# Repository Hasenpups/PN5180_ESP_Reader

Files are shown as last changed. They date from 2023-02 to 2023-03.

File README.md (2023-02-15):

[][cc-by-nc-sa]

This work is licensed under a
[Creative Commons Attribution-NonCommercial-ShareAlike 4.0 International License][cc-by-nc-sa].

[][cc-by-nc-sa]

[cc-by-nc-sa]: http://creativecommons.org/licenses/by-nc-sa/4.0/
[cc-by-nc-sa-image]: https://licensebuttons.net/l/by-nc-sa/4.0/88x31.png
[cc-by-nc-sa-shield]: https://img.shields.io/badge/License-CC%20BY--NC--SA%204.0-lightgrey.svg

## Donations / Spenden
If somebody wants to support me for upcoming projects :)  
- PayPal:  
- Amazon Giftcard: https://www.amazon.de/Amazon-Gutschein-per-E-Mail-Amazon/dp/B0054PDOV8 - stefan.riese@me.com

# PN5180 ESP reader
This reader uses a PN5180 RFID reader and a Wemos D1 mini to read RFID tags like ISO 15693.

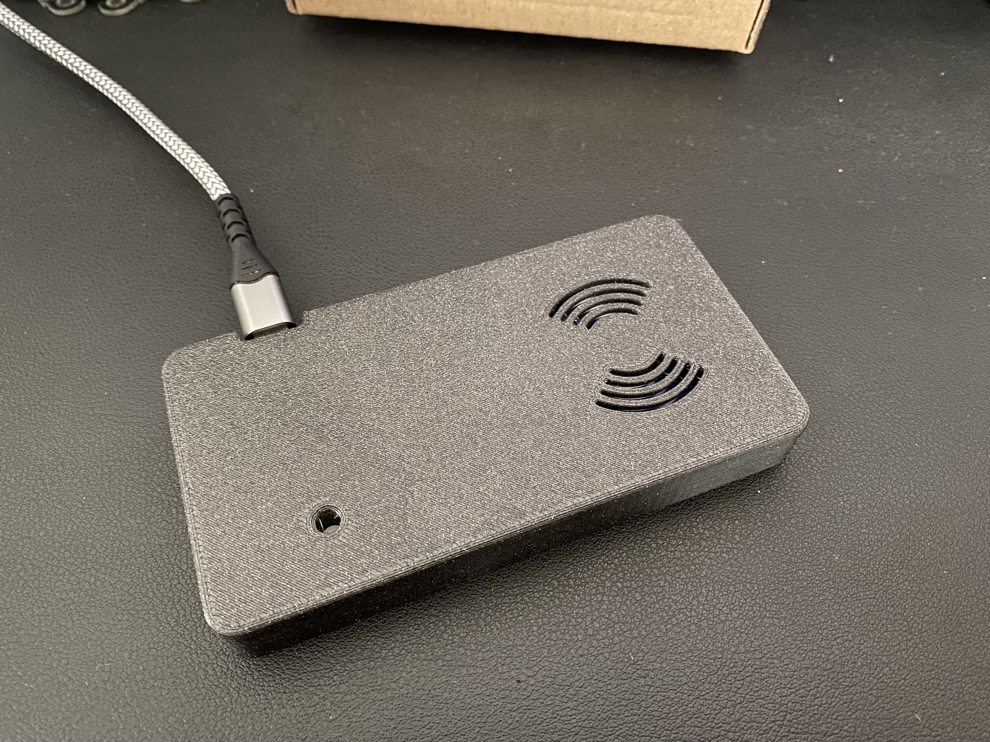
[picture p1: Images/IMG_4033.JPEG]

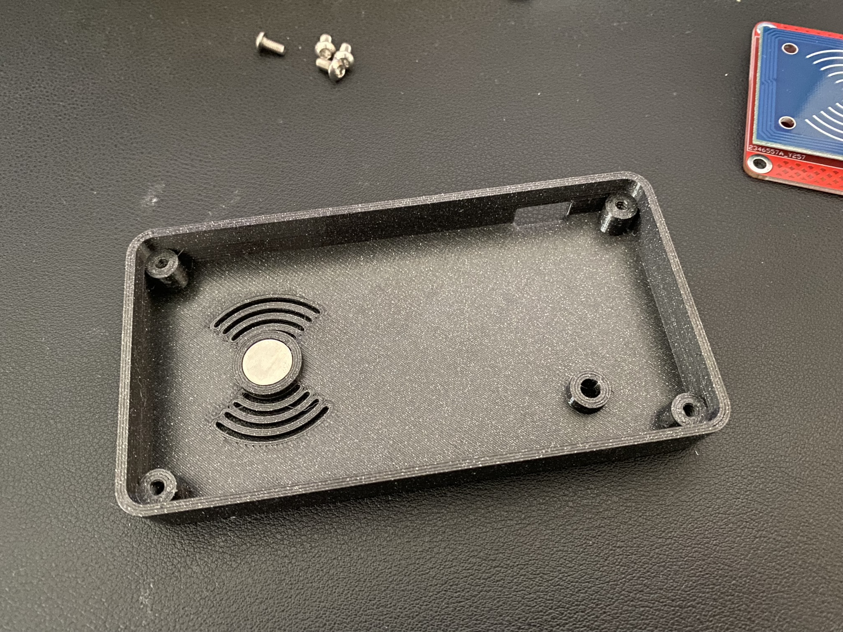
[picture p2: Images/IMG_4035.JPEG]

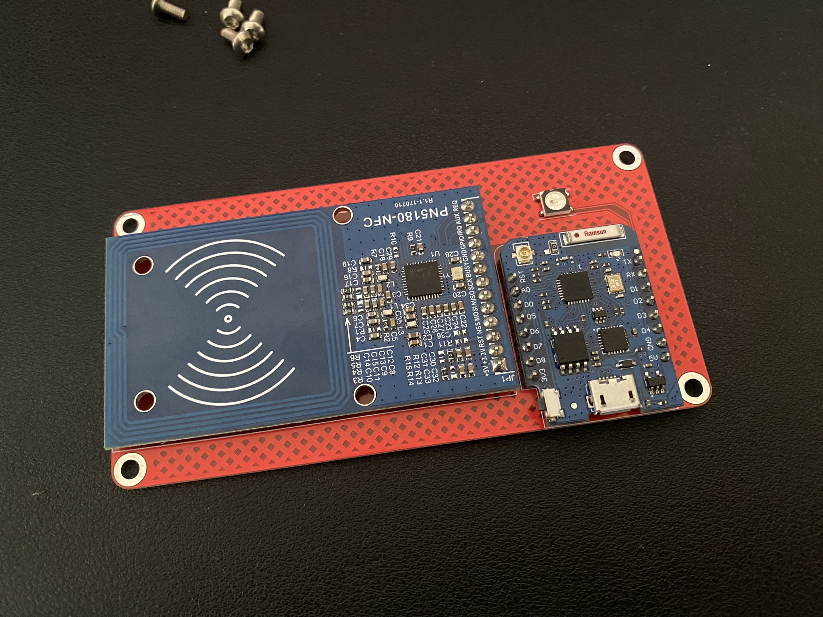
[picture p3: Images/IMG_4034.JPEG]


# Used hardware
- 1 x PN5180 reader (https://www.amazon.de/dp/B0BFGWS7MZ)
- 1 x Wemos D1 mini (https://www.amazon.de/AZDelivery-NodeMCU-ESP8266EX-kompatibel-inklusive/dp/B08BTYHJM1)
- 1 x 10x3mm magnet (https://www.amazon.de/Temporaryt-Neodym-Magnete-Aufbewahrungs-K%C3%BChlschrank/dp/B07DNBXBWQ)
- 4 x M3x6 screw

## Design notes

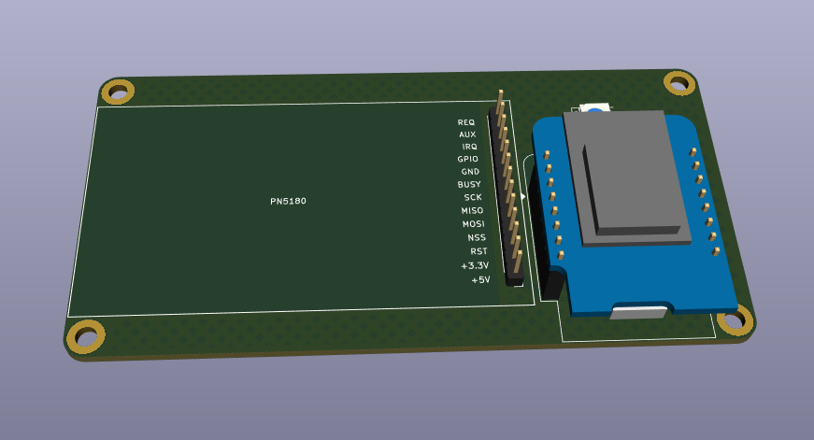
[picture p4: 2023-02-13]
PCB/PN5180_Wemos_PCB.png

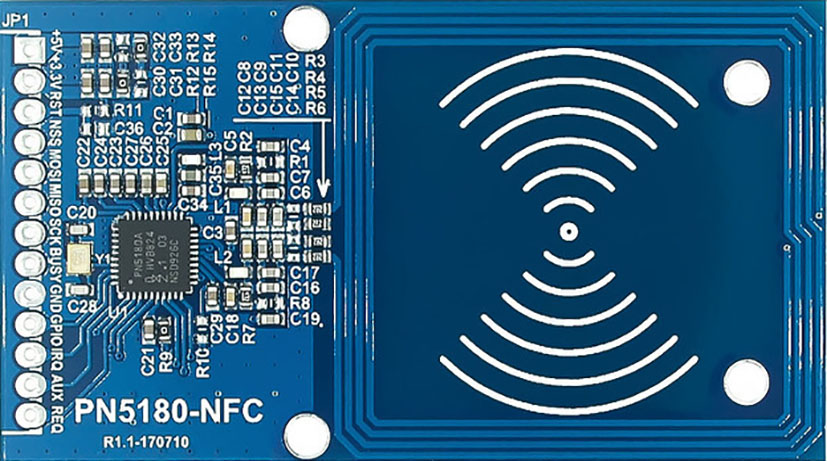
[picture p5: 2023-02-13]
PCB/PN5180-NFC-RF-Sensor-modul-Unterst-tzung-Iso15693-Hohe-Frequenz-IC-Karte-ICODE2-Reader-Schreiben.jpg

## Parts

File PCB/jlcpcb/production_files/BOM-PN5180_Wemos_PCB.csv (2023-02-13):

Comment | Designator | Footprint | LCSC
WS2812B | D1 | LED_WS2812B_PLCC4_5.0x5.0mm_P3.2mm
MountingHole | H3 | MountingHole_3.2mm_M3_DIN965_Pad
MountingHole | H2 | MountingHole_3.2mm_M3_DIN965_Pad
MountingHole | H1 | MountingHole_3.2mm_M3_DIN965_Pad
Conn_01x13_Female | PN5180 | PinHeader_1x13_P2.54mm_Vertical
WeMos_D1_mini | U1 | WEMOS_D1_mini_light
MountingHole | H4 | MountingHole_3.2mm_M3_DIN965_Pad

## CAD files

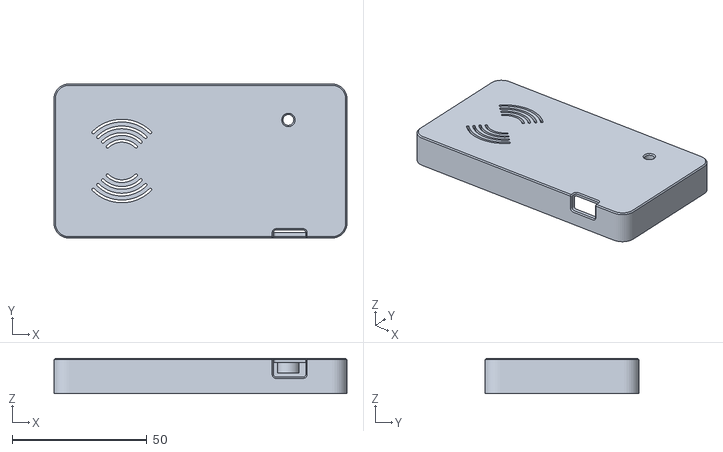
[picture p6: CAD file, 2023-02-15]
Housing/Top.stl
108.8 x 57.2 x 13.1

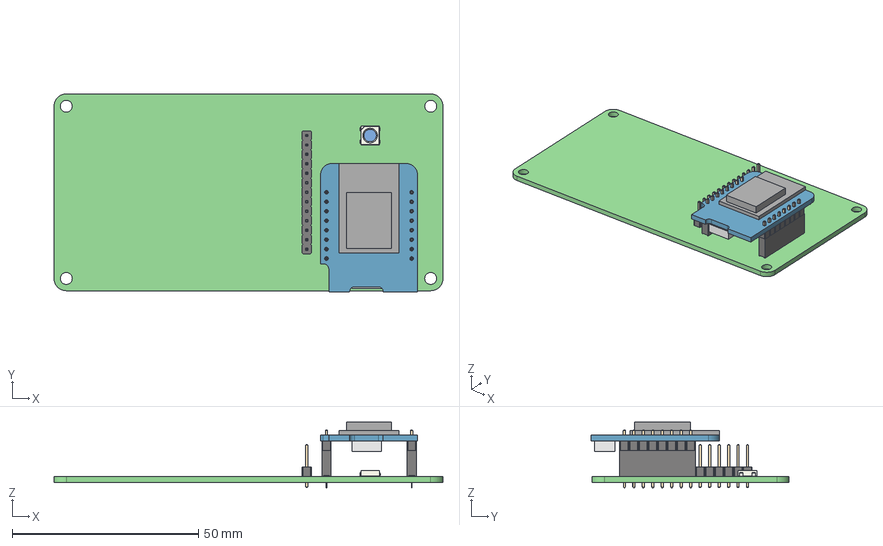
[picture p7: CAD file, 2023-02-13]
PCB/PN5180_Wemos_PCB.step
104.4 x 53.2 x 17.7 mm
PN5180_Wemos_Shield PCB

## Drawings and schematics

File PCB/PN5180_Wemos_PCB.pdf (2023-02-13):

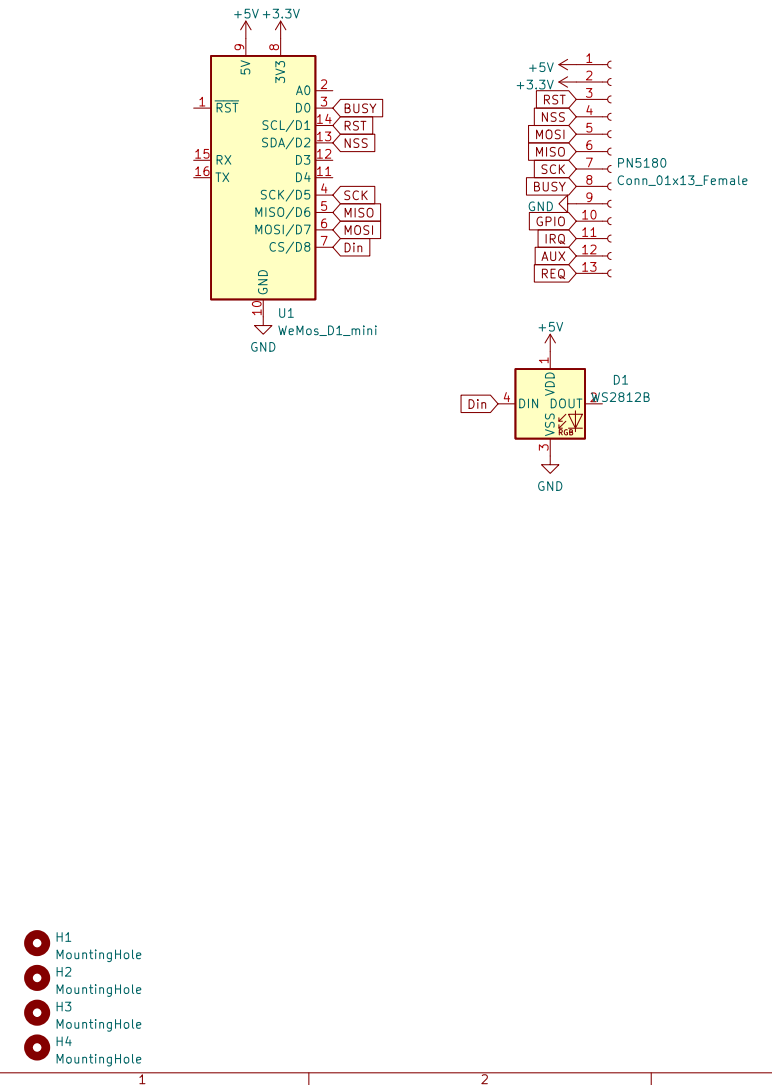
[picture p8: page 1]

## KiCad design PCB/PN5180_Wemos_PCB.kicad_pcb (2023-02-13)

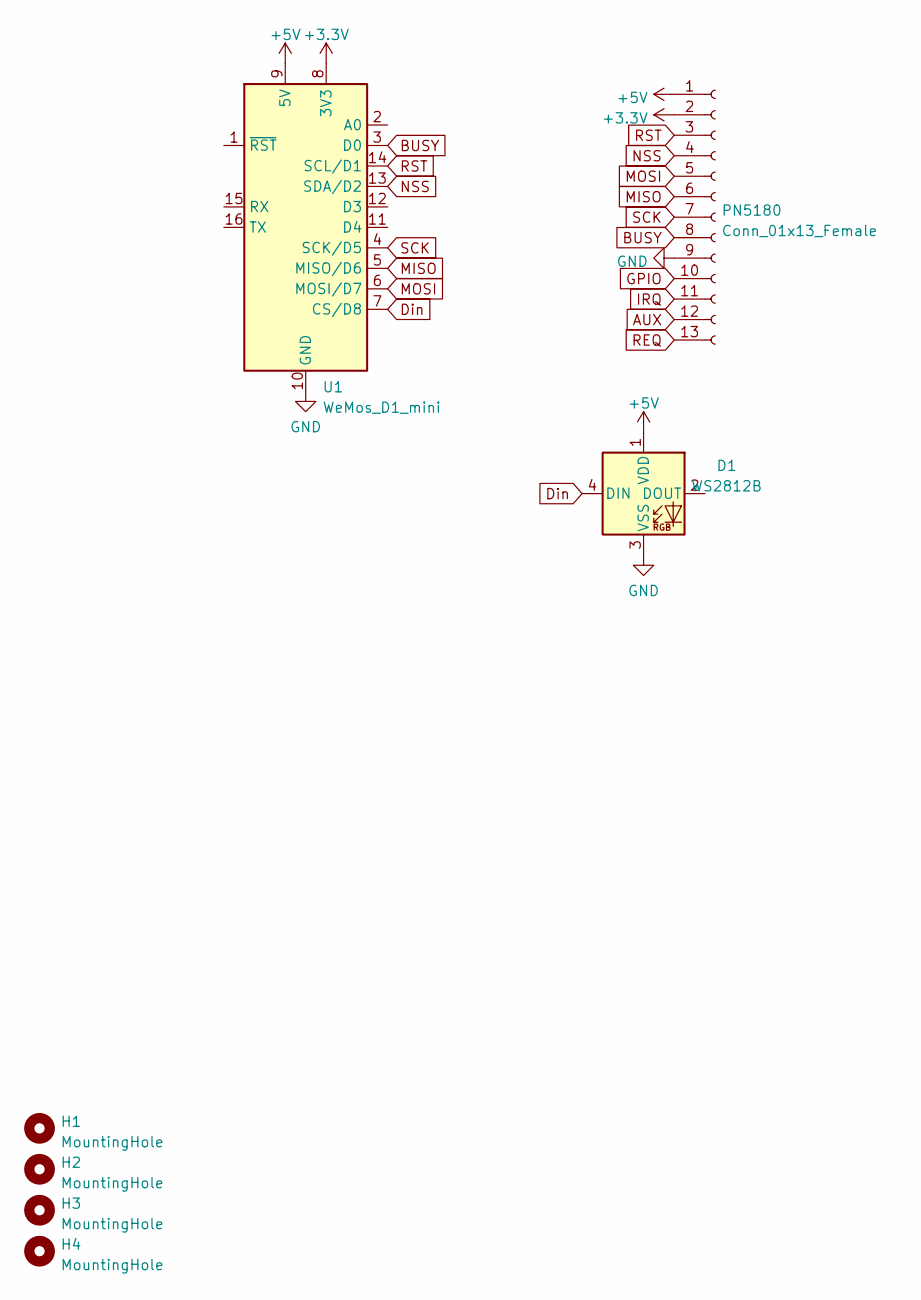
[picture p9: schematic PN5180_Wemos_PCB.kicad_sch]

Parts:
D1: WS2812B; LED_WS2812B_PLCC4_5.0x5.0mm_P3.2mm
H1, H2, H3, H4: MountingHole; MountingHole_3.2mm_M3_DIN965_Pad
PN5180: Conn_01x13_Female; PinHeader_1x13_P2.54mm_Vertical
U1: WeMos_D1_mini; WEMOS_D1_mini_light

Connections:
+3.3V: PN5180.2, U1.8 (3V3)
+5V: D1.1 (VDD), PN5180.1, U1.9 (5V)
AUX: PN5180.12
BUSY: PN5180.8, U1.3 (D0)
Din: D1.4 (DIN), U1.7 (CS/D8)
GND: D1.3 (VSS), PN5180.9, U1.10 (GND)
GPIO: PN5180.10
IRQ: PN5180.11
MISO: PN5180.6, U1.5 (MISO/D6)
MOSI: PN5180.5, U1.6 (MOSI/D7)
NSS: PN5180.4, U1.13 (SDA/D2)
REQ: PN5180.13
RST: PN5180.3, U1.14 (SCL/D1)
SCK: PN5180.7, U1.4 (SCK/D5)

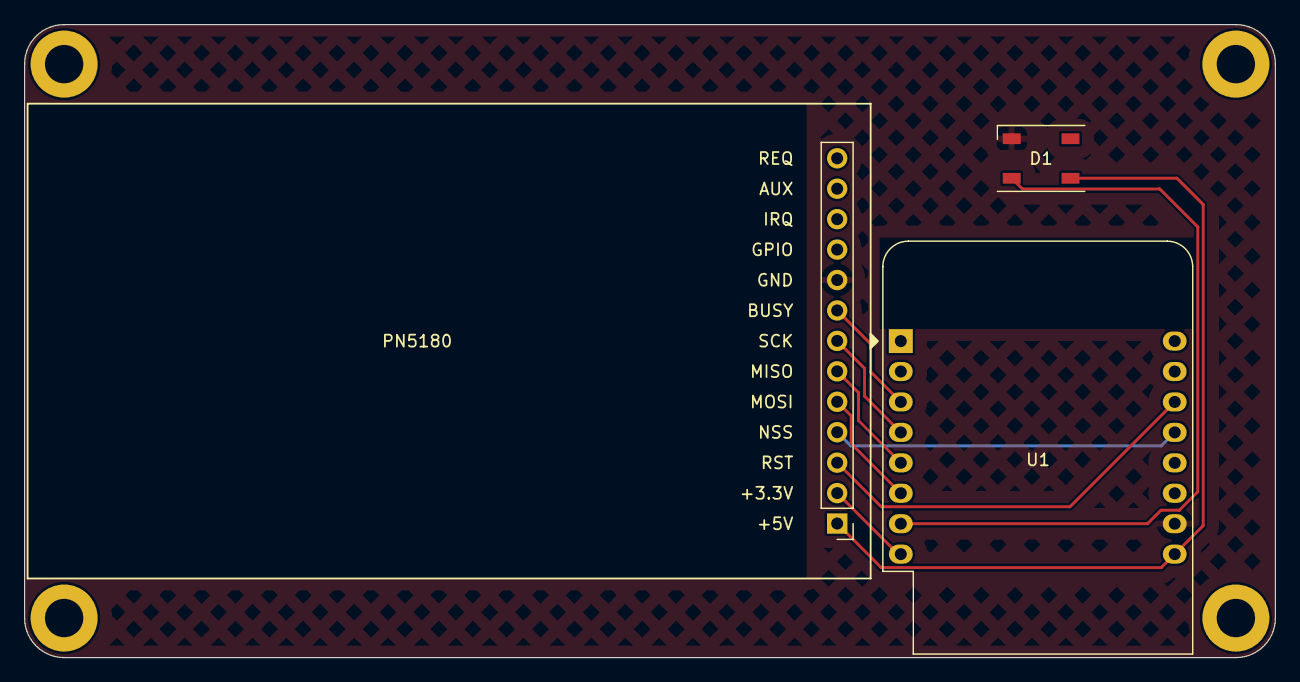
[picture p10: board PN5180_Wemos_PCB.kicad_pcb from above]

Board: 2 copper layers, 104.4 x 52.8 mm, 7 parts (0 on the bottom side), 10 nets.

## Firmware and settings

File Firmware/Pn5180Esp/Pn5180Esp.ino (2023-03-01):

/**************************************************
  Includes
**************************************************/
#include <PN5180ISO15693.h>
#include <Adafruit_NeoPixel.h>

/**************************************************
  Defines
**************************************************/
#define VERSION "1.0"
#define SKETCHNAME "Pn5180Esp"
#define LED_BRIGHTNESS 10

#if defined(ARDUINO_AVR_UNO) || defined(ARDUINO_AVR_MEGA2560) || defined(ARDUINO_AVR_NANO)

#define PN5180_NSS  10
#define PN5180_BUSY 9
#define PN5180_RST  7

#elif defined(ARDUINO_ARCH_ESP32)

#define PN5180_NSS  16
#define PN5180_BUSY 5
#define PN5180_RST  17

#elif defined(ARDUINO_ARCH_ESP8266)

#define PN5180_NSS 4
#define PN5180_BUSY 16
#define PN5180_RST 5
#define WS2812B_PIN D8

#else
#error Please define your pinout here!
#endif

/**************************************************
  Variables
**************************************************/
PN5180ISO15693 nfc15693(PN5180_NSS, PN5180_BUSY, PN5180_RST);
uint8_t password[] = {0x0F, 0x0F, 0x0F, 0x0F};      // default password
uint8_t password2[] = {0x5B, 0x6E, 0xFD, 0x7F}; // t***e password
Adafruit_NeoPixel pixels = Adafruit_NeoPixel(1, WS2812B_PIN, NEO_GRB + NEO_KHZ800);

/*************************************
  Setup
*************************************/
void setup()
{
  pixels.begin();
  ledFeedback(LED_BRIGHTNESS,LED_BRIGHTNESS,LED_BRIGHTNESS,100);

  Serial.setTimeout(50);
  Serial.begin(115200);
  Serial.println(F("=================================="));
  Serial.println(F("Uploaded: " __DATE__ " " __TIME__));
  Serial.println(F("PN5180 NFC15693 Demo Sketch"));

  nfc15693.begin();

  Serial.println(F("----------------------------------"));
  Serial.println(F("PN5180 Hard-Reset..."));
  nfc15693.reset();

  Serial.println(F("----------------------------------"));
  Serial.println(F("Reading product version..."));
  uint8_t productVersion[2];
  nfc15693.readEEprom(PRODUCT_VERSION, productVersion, sizeof(productVersion));
  Serial.print(F("Product version="));
  Serial.print(productVersion[1]);
  Serial.print(".");
  Serial.println(productVersion[0]);

  if (0xff == productVersion[1]) { // if product version 255, the initialization failed
    Serial.println(F("Initialization failed!?"));
    Serial.println(F("Press reset to restart..."));
    Serial.flush();
    exit(-1); // halt
  }

  Serial.println(F("----------------------------------"));
  Serial.println(F("Reading firmware version..."));
  uint8_t firmwareVersion[2];
  nfc15693.readEEprom(FIRMWARE_VERSION, firmwareVersion, sizeof(firmwareVersion));
  Serial.print(F("Firmware version="));
  Serial.print(firmwareVersion[1]);
  Serial.print(".");
  Serial.println(firmwareVersion[0]);

  Serial.println(F("----------------------------------"));
  Serial.println(F("Reading EEPROM version..."));
  uint8_t eepromVersion[2];
  nfc15693.readEEprom(EEPROM_VERSION, eepromVersion, sizeof(eepromVersion));
  Serial.print(F("EEPROM version="));
  Serial.print(eepromVersion[1]);
  Serial.print(".");
  Serial.println(eepromVersion[0]);

  Serial.println(F("----------------------------------"));
  Serial.println(F("Enable RF field..."));
  nfc15693.setupRF();
}

/*************************************
  Loop
*************************************/
void loop()
{
  serialInterface();
}

/**************************************************
  Serial interface for communication to the PC
**************************************************/
void serialInterface()
{
  // handle input strings
  if (Serial.available())
  {
    // read the string from the interface
    String command = Serial.readString();

    // handle command
    handleCommand(command);
  }
}

void handleCommand(String command)
{
  String response = "";
  uint8_t uid[10];

  // handle the command
  if (command.startsWith("v"))
  {
    response = (String)SKETCHNAME + " - " + (String)VERSION;
    Serial.println(response);
  }
  else if (command.startsWith("u"))
  {
    nfc15693.reset();
    nfc15693.setupRF();
    delay(50);

    // try to unlock with t***e password
    ISO15693ErrorCode myrc = nfc15693.disablePrivacyMode(password2);
    if (ISO15693_EC_OK == myrc)
    {
      Serial.println("ok");
      ledFeedback(0,LED_BRIGHTNESS,0,100);
      return;
    }
    else
    {
      nfc15693.reset();
      nfc15693.setupRF();
      delay(50);

      //try to unlock with default password");
      ISO15693ErrorCode myrc = nfc15693.disablePrivacyMode(password);
      if (ISO15693_EC_OK == myrc)
      {
        Serial.println("ok");
        ledFeedback(0,LED_BRIGHTNESS,0,100);
        return;
      }
    }
    
    Serial.println("nok");
    ledFeedback(LED_BRIGHTNESS,0,0,100);
  }
  else if (command.startsWith("l"))
  {
    Serial.println("nok");
  }
  else if (command.startsWith("i"))
  {
    nfc15693.reset();
    nfc15693.setupRF();
    delay(50);

    // try to read ISO15693 inventory
    ISO15693ErrorCode rc = nfc15693.getInventory(uid);
    if (rc == ISO15693_EC_OK)
    {
      for (int i = 0; i < 8; i++)
      {
        response = response + (uid[7 - i] < 0x10 ? "0" : "");
        response = response + String(uid[7 - i], HEX);

      }
      response.toUpperCase();

      ledFeedback(0,LED_BRIGHTNESS,0,100);
    }
    else
    {
      ledFeedback(LED_BRIGHTNESS,0,0,100);
    }

    Serial.println(response);
  }
}

void ledFeedback(int r, int g, int b, int delayMs)
{
  pixels.setPixelColor(0, pixels.Color(r, g, b));
  pixels.show();
  delay(delayMs);
  pixels.setPixelColor(0, pixels.Color(0, 0, 0));
  pixels.show();
}

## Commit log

2023-02-13 - initial commit
    [BOM-PN5180_Wemos_PCB.csv, PN5180_Wemos_PCB.kicad_pcb, PN5180_Wemos_PCB.kicad_sch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]
2023-02-15 - restructure files
    [BOM-PN5180_Wemos_PCB.csv, PN5180_Wemos_PCB.kicad_pcb, PN5180_Wemos_PCB.kicad_sch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]

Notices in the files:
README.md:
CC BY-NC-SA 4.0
